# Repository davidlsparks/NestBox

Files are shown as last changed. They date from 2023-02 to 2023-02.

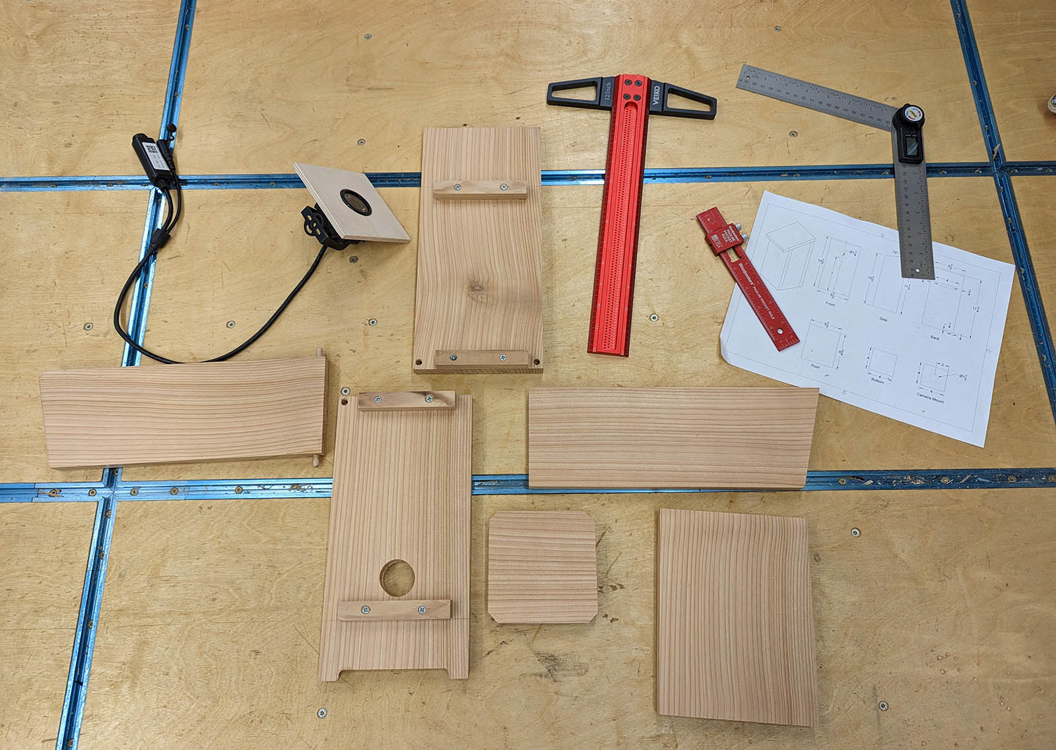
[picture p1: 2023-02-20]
images/nestbox_components.jpg

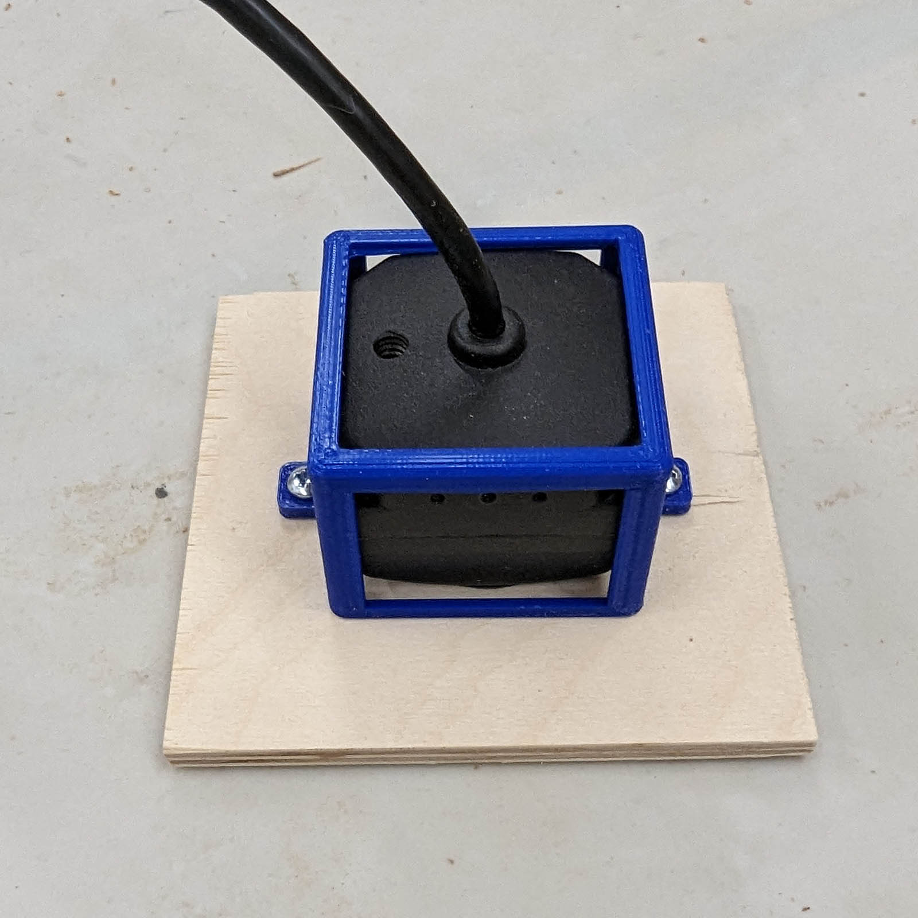
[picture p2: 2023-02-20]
images/nestbox_camera_mount.jpg

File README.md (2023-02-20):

# NestBox

## Introduction

This nest box is designed for chickadees, wrens, and other small birds. The entrance is 1-1/4" (~32mm) which should keep starlings and other larger birds out. For extra protection, you can glue or nail a piece of hardwood over the entrance, as you'll see in the image I provided of the fully assembled box.

## Camera

I purchased a relatively inexpensive camera on Aliexpress. There are a number of vendors who sell the same or similar product under other names. I chose the 5MP with a 2.8mm lens.

https://www.aliexpress.us/item/3256802313550603.html

If you purchase a different camera, you'll probably need to modify the camera mount and clamp. If running an Ethernet cable is an issue, this camera also supports WiFi. There's enough room above the camera mount to put a decent size battery inside, or you can run a DC power adapter into it.

## Material

I used 1x6 cedar for all the wood parts except for the hole reinforcement plate, which is white oak. The parts diagram assumes a true 3/4" thickness and 5-1/2" width. My cedar was undersized at 11/16" and I ran it through a planar to clean it up, taking it down to 5/8".

If your material is a different thickness, you'll need to adjust the width of the front back and roof appropriately. For example, for 5/8" material, my front and back were cut to 5-1/4" instead of 5-1/2". I left the roof at 5-1/2" so it's slightly proud on both sides.

## Assembly

Assembly is pretty straightforward. I drilled out the holes for the dowel pin hinges. I chose to glue the dowel pins into the side rather than the front and back. I also attached cleats to the front and back to support the floor and simplify the assembly.

I recommend using a water-resistant glue like Titebond III if you are planning to glue it together. I used glue and then tacked everything down with a pin nailer. Screws will also work - I suggest stainless or coated to prevent corrosion.

I recommend not attaching the camera mount plate to the box. I undersized the mount plate slightly so I can pull it out and replace the camera.

I also cut a 1/4" vent on the front just below the roof to allow for some circulation. I used a 1/2" straight bit on the router table, but a jigsaw, coping saw, or chisel would also work.

## Floor
I recommend you make some accommodation for drainage in the floor. While the box itself should be reasonably water tight, it might get water sogged during a long rain. I cut a 45 degree about 1/2" in from each corner of the floor. Alternatively, you could drill holes in the corners - a 3/8" hole should suffice.

## Ventilation
If you live in an area where it gets warm during nesting season, or if the box is subject to direct exposure to afternoon sun, you might want to add some ventilation to the sides of the box. This could be a 1/4" slot in each side just below the camera mount, or a series of holes.

## 3D Printed Parts

I have included .STP and .STL files for the 3D printed parts. These are optional. You can buy hardware or fabricate them from wood instead.

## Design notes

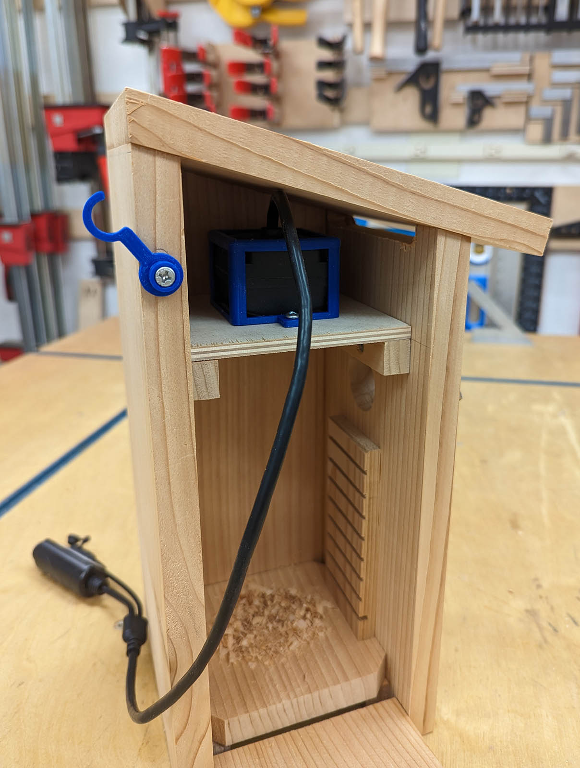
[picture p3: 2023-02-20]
images/nestbox_internal.jpg

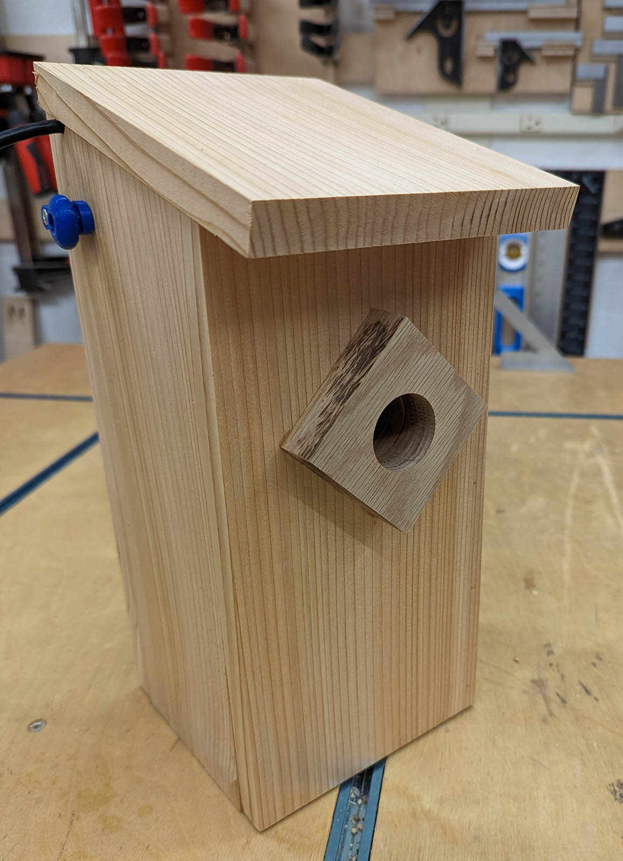
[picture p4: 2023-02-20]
images/nestbox_external.jpg

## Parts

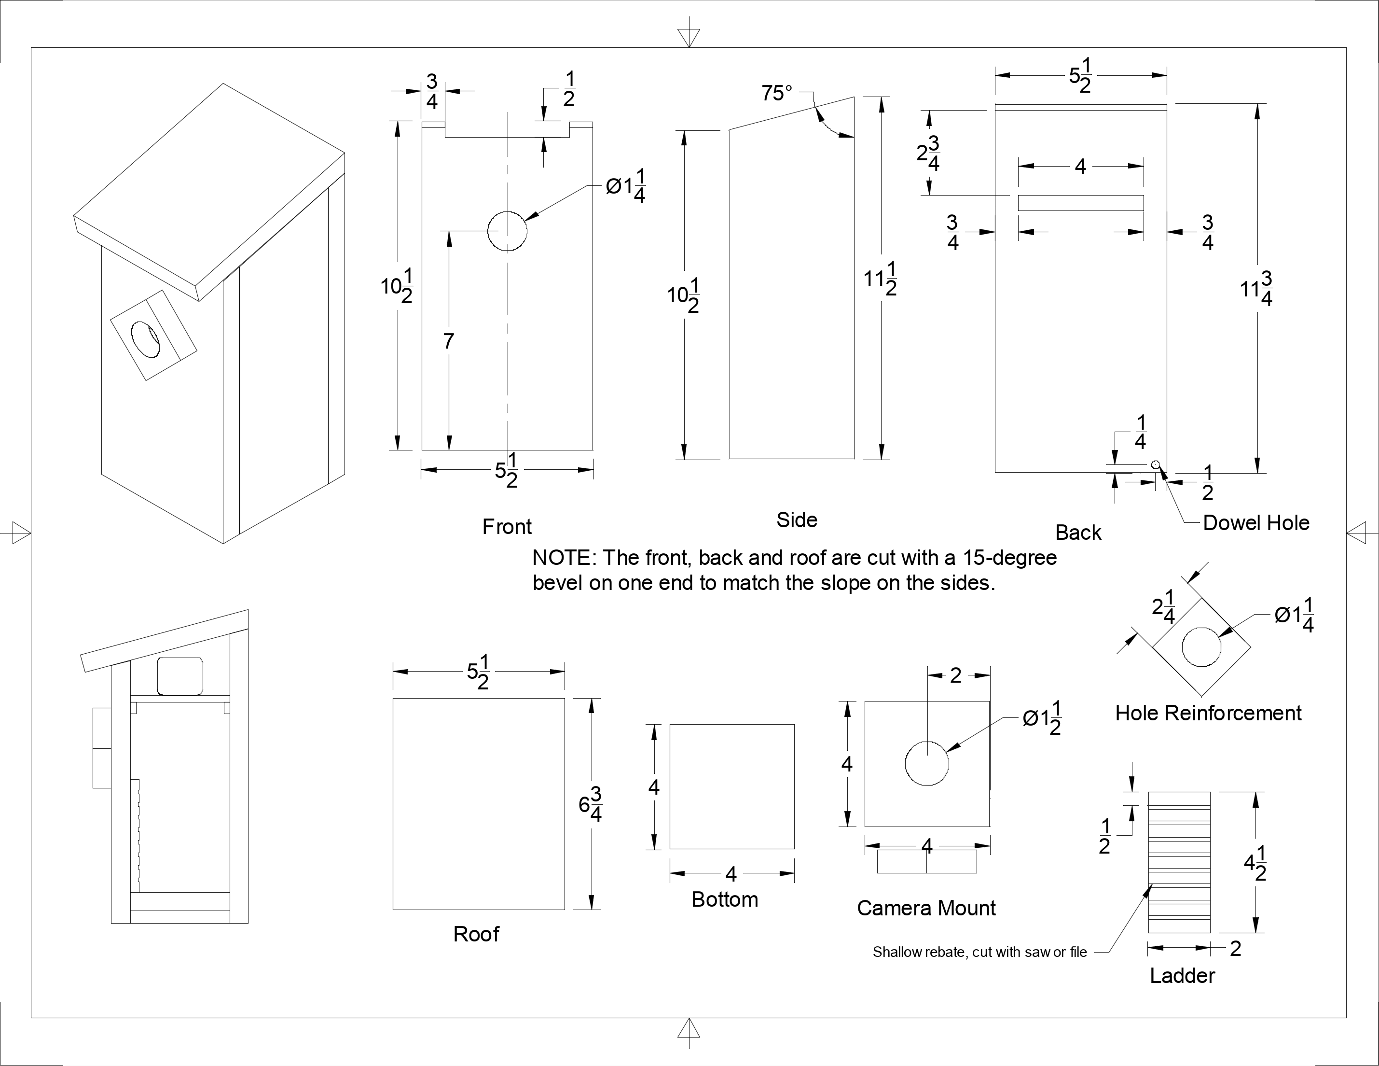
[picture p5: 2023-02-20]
images/Nest Box Parts Drawing.png

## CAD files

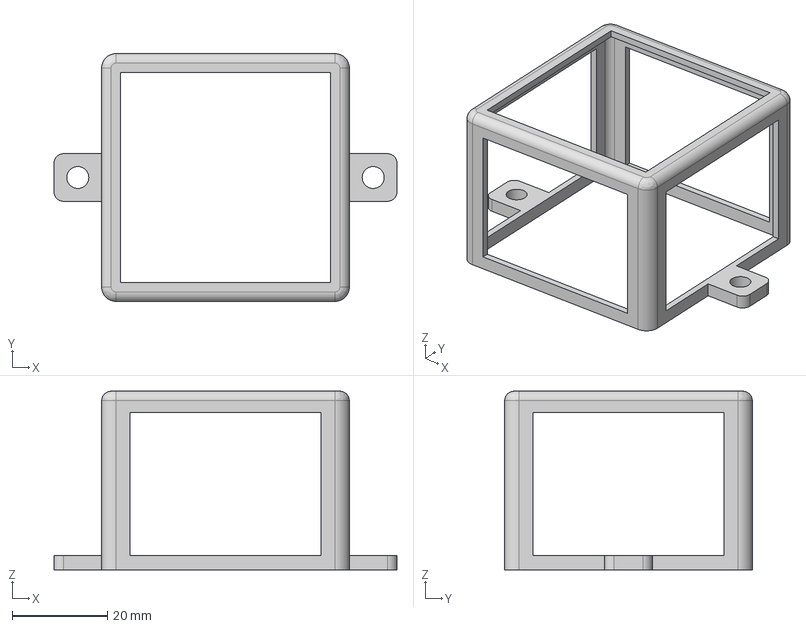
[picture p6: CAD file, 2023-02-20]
CAD/Nest Box Camera Holder.step
72.0 x 52.0 x 37.5 mm

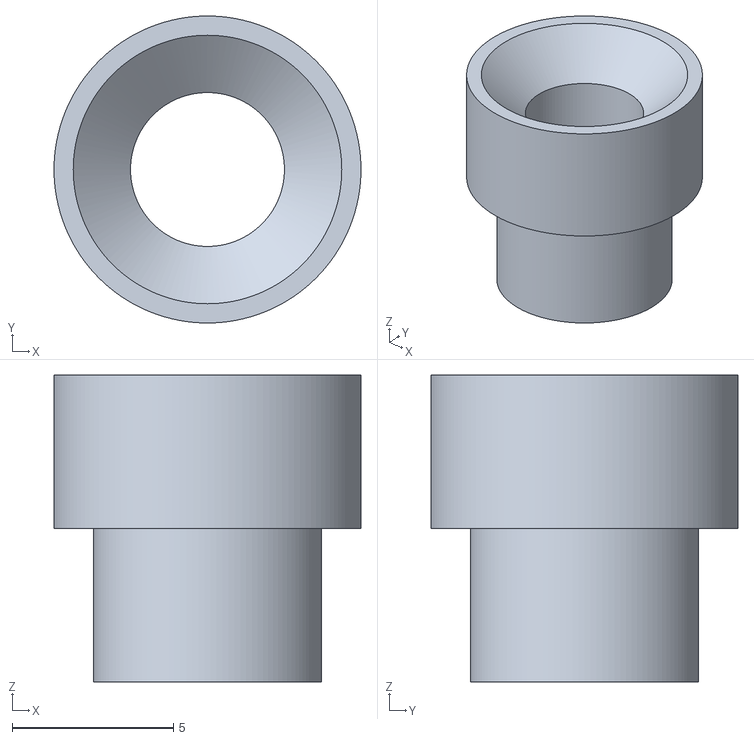
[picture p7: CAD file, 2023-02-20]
STL/pin.stl
9.52 x 9.52 x 9.52

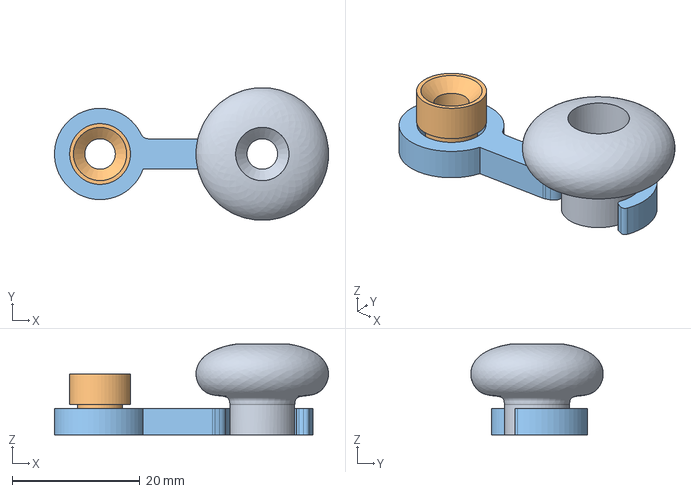
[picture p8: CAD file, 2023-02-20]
CAD/Nest Box Hardware.step
42.9 x 20.7 x 14.2 mm
Handle
Latch

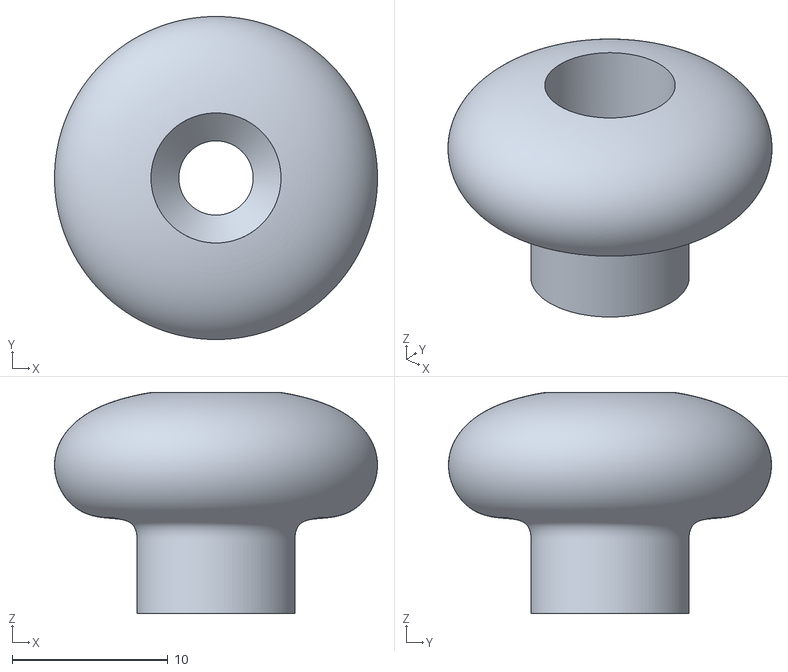
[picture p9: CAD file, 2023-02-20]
STL/knob.stl
20.8 x 20.8 x 14.2

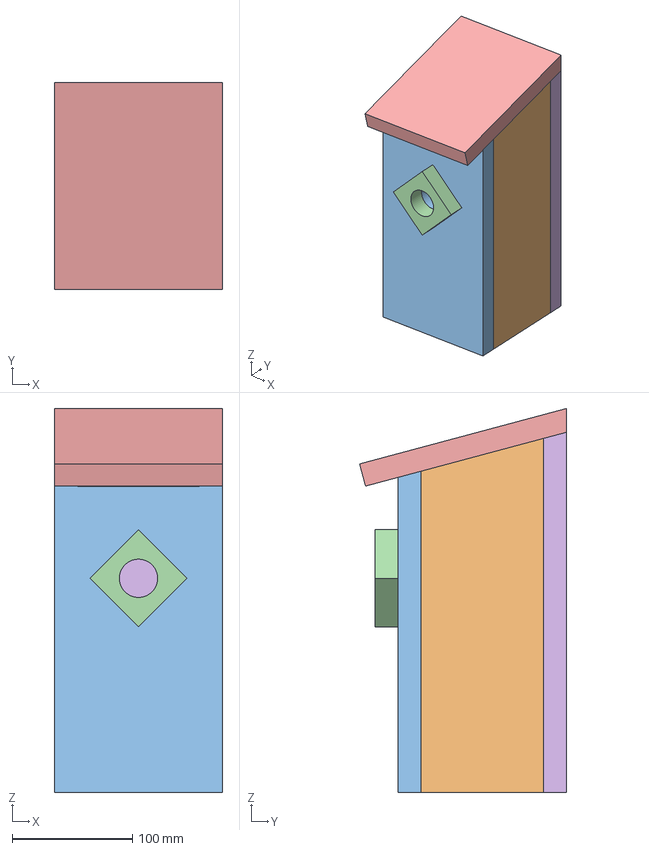
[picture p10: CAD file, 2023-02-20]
CAD/Nest Box with Camera.step
139.7 x 171.7 x 318.8 mm
Nest Box Camera
Right Side

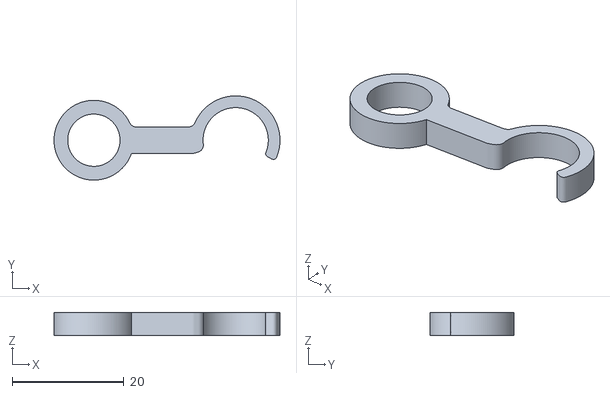
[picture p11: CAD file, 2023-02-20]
STL/latch.stl
40.5 x 15.1 x 4.13

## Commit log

2023-02-20 Add Step file for Nest Box
    [Nest Box with Camera.step]
2023-02-20 Add step file for 3D printed hardware
    [Nest Box Hardware.step]
2023-02-20 Add step file for camera holder
    [Nest Box Camera Holder.step]
2023-02-20 Add STL files for hardware
    [knob.stl, latch.stl, pin.stl]
2023-02-20 Add assembly images
